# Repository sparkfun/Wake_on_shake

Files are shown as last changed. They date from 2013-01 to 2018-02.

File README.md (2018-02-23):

Wake on Shake
=============

[Wake on Shake  
*Wake on Shake (SEN-11447)*](https://www.sparkfun.com/products/11447)

The Wake-on-Shake, based on a concept by Nitzan Gadish of Analog Devices, combines the ATTiny2313A with the ADXL362 
low-power accelerometer to cut power to your project for long periods of time, all the while waiting for a shake or a bump and sipping <2uA at 3.7V

Wake-on-Shake firmware was compiled in WinAVR-20100110.  
Arduino example sketch was compiled in Arduino 1.6. 
Hardware was developed in EAGLE 6.3.0.

Repository Contents
-------------------

* **/Firmware** - Any firmware that the part ships with, 
* **/Hardware** - All Eagle design files (.brd, .sch, .STL)
* **/Production** - Test bed files and production panel files

Documentation
--------------
* **[Hookup Guide](https://learn.sparkfun.com/tutorials/wake-on-shake-hookup-guide)** - Basic hookup guide for the Wake-on-Shake.
* **[Project Tutorial](https://learn.sparkfun.com/tutorials/the-uncertain-7-cube)** - Project tutorial for the Wake-on-Shake.
  
License Information
-------------------
The hardware is released under [Creative Commons ShareAlike 4.0 International](https://creativecommons.org/licenses/by-sa/4.0/).
The code is beerware; if you see me (or any other SparkFun employee) at the local, and you've found our code helpful, please buy us a round!

Distributed as-is; no warranty is given.

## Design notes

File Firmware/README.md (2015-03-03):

Wake-on-Shake Firmware
========================

* **Neopixel_Wake-on-Shake_Demo** -Example Arduino Sketch using the Neopixel library.
* **SparkFun_Wake-on-Shake_Demo** -Example Arduino Sketch for basic LED control.
* **Wake-on-Shake_Firmware** -Firmware that comes preinstalled on the SparkFun Wake-on-Shake.

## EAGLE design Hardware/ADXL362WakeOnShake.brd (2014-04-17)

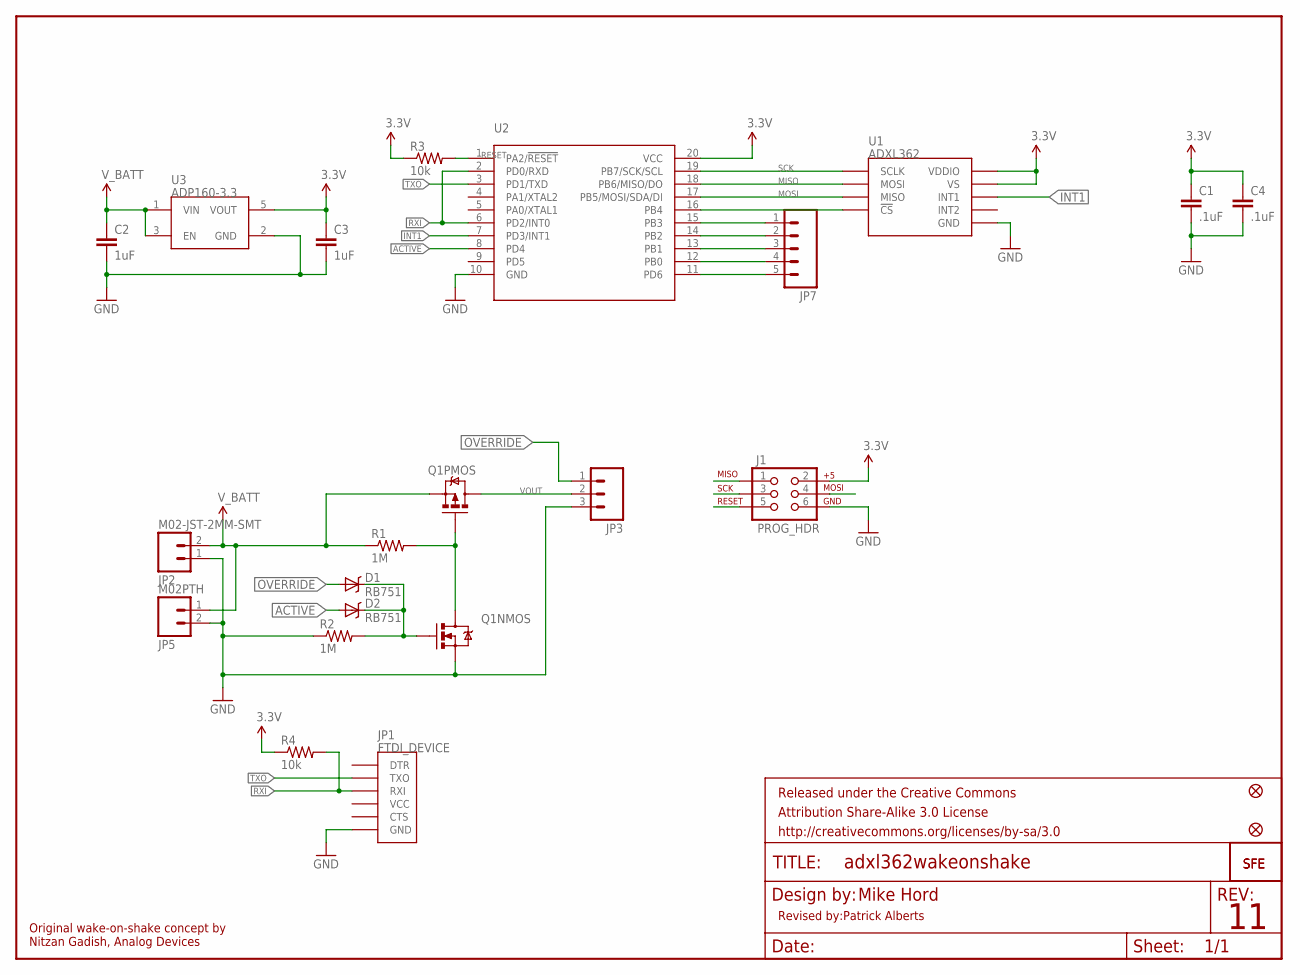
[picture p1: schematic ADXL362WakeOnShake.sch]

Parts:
C1, C4: .1uF; 0603-CAP
C2, C3: 1uF; 0603-CAP
D1, D2: RB751; SOD-523
FID1, FID2: FIDUCIAL1X2; FIDUCIAL-1X2
FRAME1: FRAME-LETTER; CREATIVE_COMMONS
J1: PROG_HDR; 2X3
JP1: FTDI_DEVICE; FTDI_DEVICE_SIDE
JP2: M02-JST-2MM-SMT; JST-2-SMD
JP3: M03PTH; 1X03
JP4: LOGO-SFENW2; SFE-NEW-WEB
JP5: M02PTH; 1X02
JP6: LOGO-SFENEW; SFE-NEW-WEBLOGO
JP7: M05PTH; 1X05
Q1: IRF7509; MSOP8
R1, R2: 1M; 0603-RES
R3, R4: 10k; 0603-RES
U1: ADXL362; ADXL362-1:1
U2: ATTINY2313A; SOP20W
U3: ADP160-3.3; SOT23-5

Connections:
3.3V: C1.1, C3.1, C4.1, J1.2, R3.1, R4.1, U1.P$1 (VDDIO), U1.P$14 (VS), U2.20 (VCC), U3.5 (VOUT)
ACTIVE: D2.A, U2.8 (PD4)
GND: C1.2, C2.2, C3.2, C4.2, J1.6, JP1.P$6 (GND), JP2.1 (2), JP3.3, JP5.2, Q1.1 (S), R2.1, U1.P$12 (GND), U1.P$13 (GND), U1.P$16 (GND), U2.10 (GND), U3.2 (GND)
INT1: U1.P$11 (INT1), U2.7 (PD3/INT1)
MISO: J1.1, U1.P$6 (MOSI), U2.18 (PB6/MISO/DO)
MOSI: J1.4, U1.P$7 (MISO), U2.17 (PB5/MOSI/SDA/DI)
unnamed: Q1.4 (G), Q1.7 (D), Q1.8 (D), R1.2
unnamed: D1.C, D2.C, Q1.2 (G), R2.2
unnamed: JP7.1, U2.15 (PB3)
unnamed: JP7.2, U2.14 (PB2)
unnamed: JP7.3, U2.13 (PB1)
unnamed: JP7.4, U2.12 (PB0)
unnamed: U1.P$8 (!CS), U2.16 (PB4)
unnamed: JP7.5, U2.11 (PD6)
OVERRIDE: D1.A, JP3.1
RESET: J1.5, R3.2, U2.1 (PA2/!RESET)
RXI: JP1.P$3 (RXI), R4.2, U2.2 (PD0/RXD), U2.6 (PD2/INT0)
SCK: J1.3, U1.P$4 (SCLK), U2.19 (PB7/SCK/SCL)
TXO: JP1.P$2 (TXO), U2.3 (PD1/TXD)
VOUT: JP3.2, Q1.5 (D), Q1.6 (D)
V_BATT: C2.1, JP2.2 (1), JP5.1, Q1.3 (S), R1.1, U3.1 (VIN), U3.3 (EN)

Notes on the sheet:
Mike Hord
Original wake-on-shake concept by Nitzan Gadish, Analog Devices
Revised by:Patrick Alberts

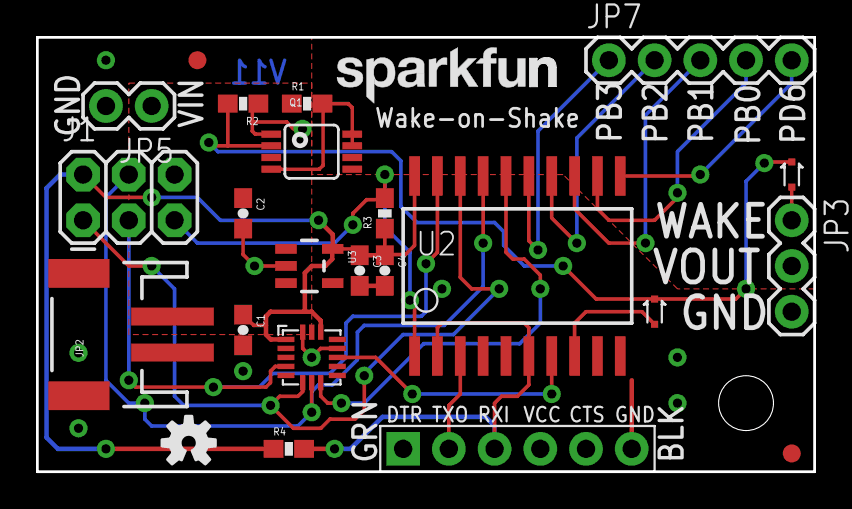
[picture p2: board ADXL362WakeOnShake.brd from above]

Board: 2 copper layers, 43.2 x 24.1 mm, 27 parts (1 on the bottom side), 21 nets.

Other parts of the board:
U$3: OSHW-LOGO-S
U$4: STAND-OFF-TIGHT

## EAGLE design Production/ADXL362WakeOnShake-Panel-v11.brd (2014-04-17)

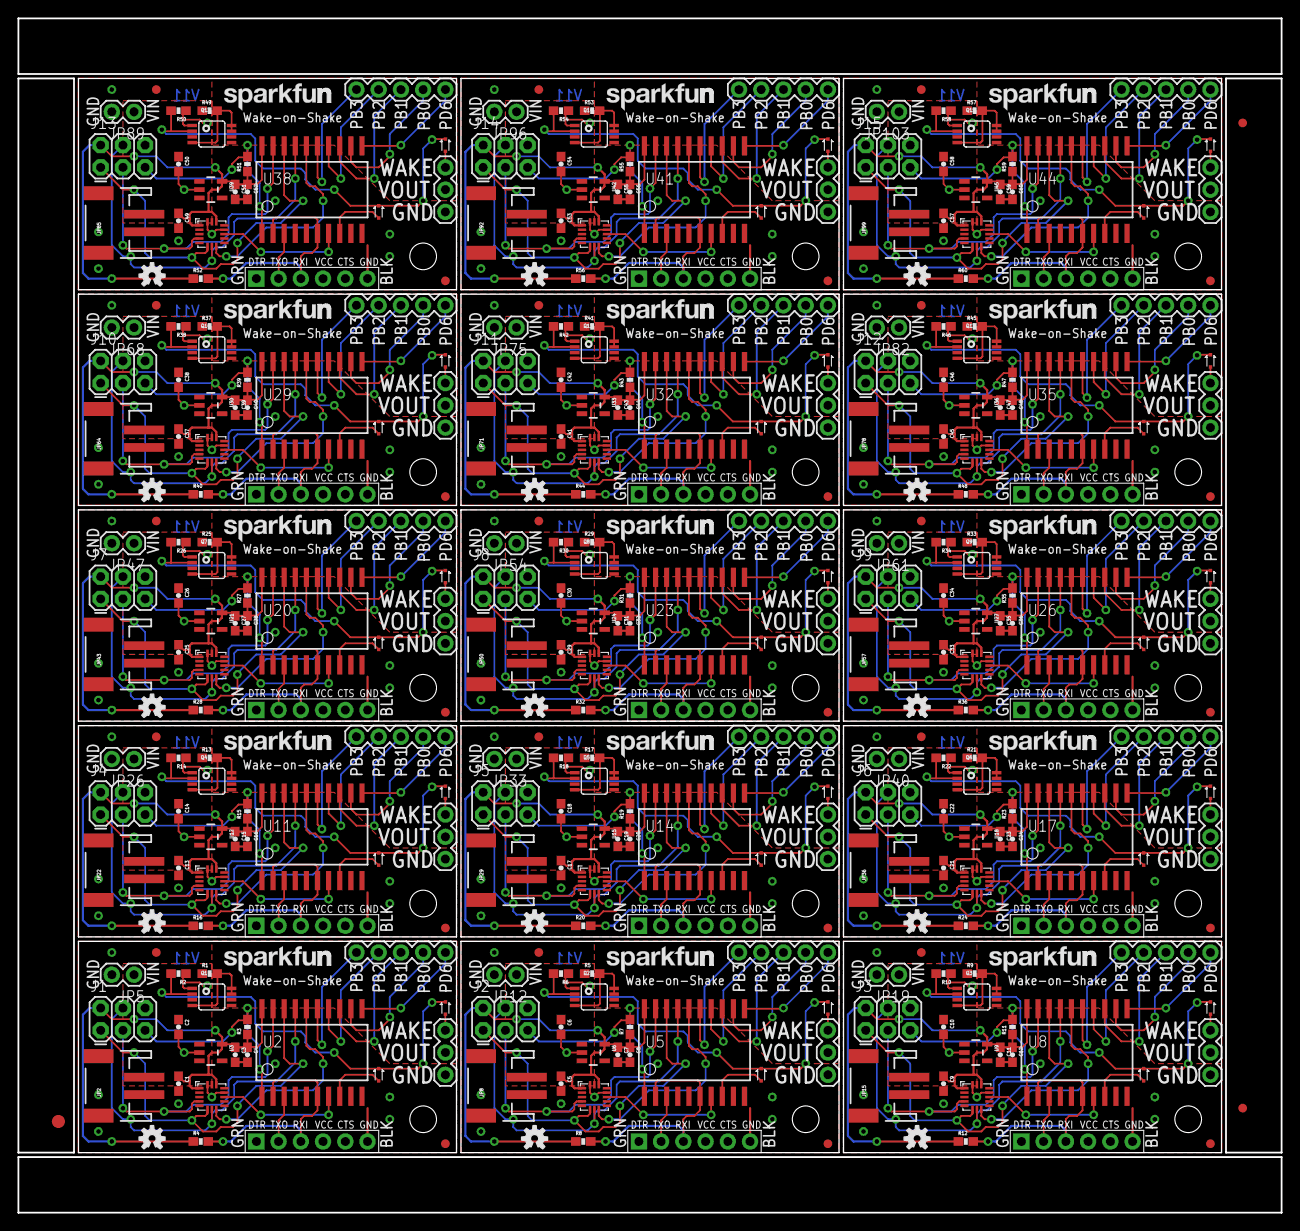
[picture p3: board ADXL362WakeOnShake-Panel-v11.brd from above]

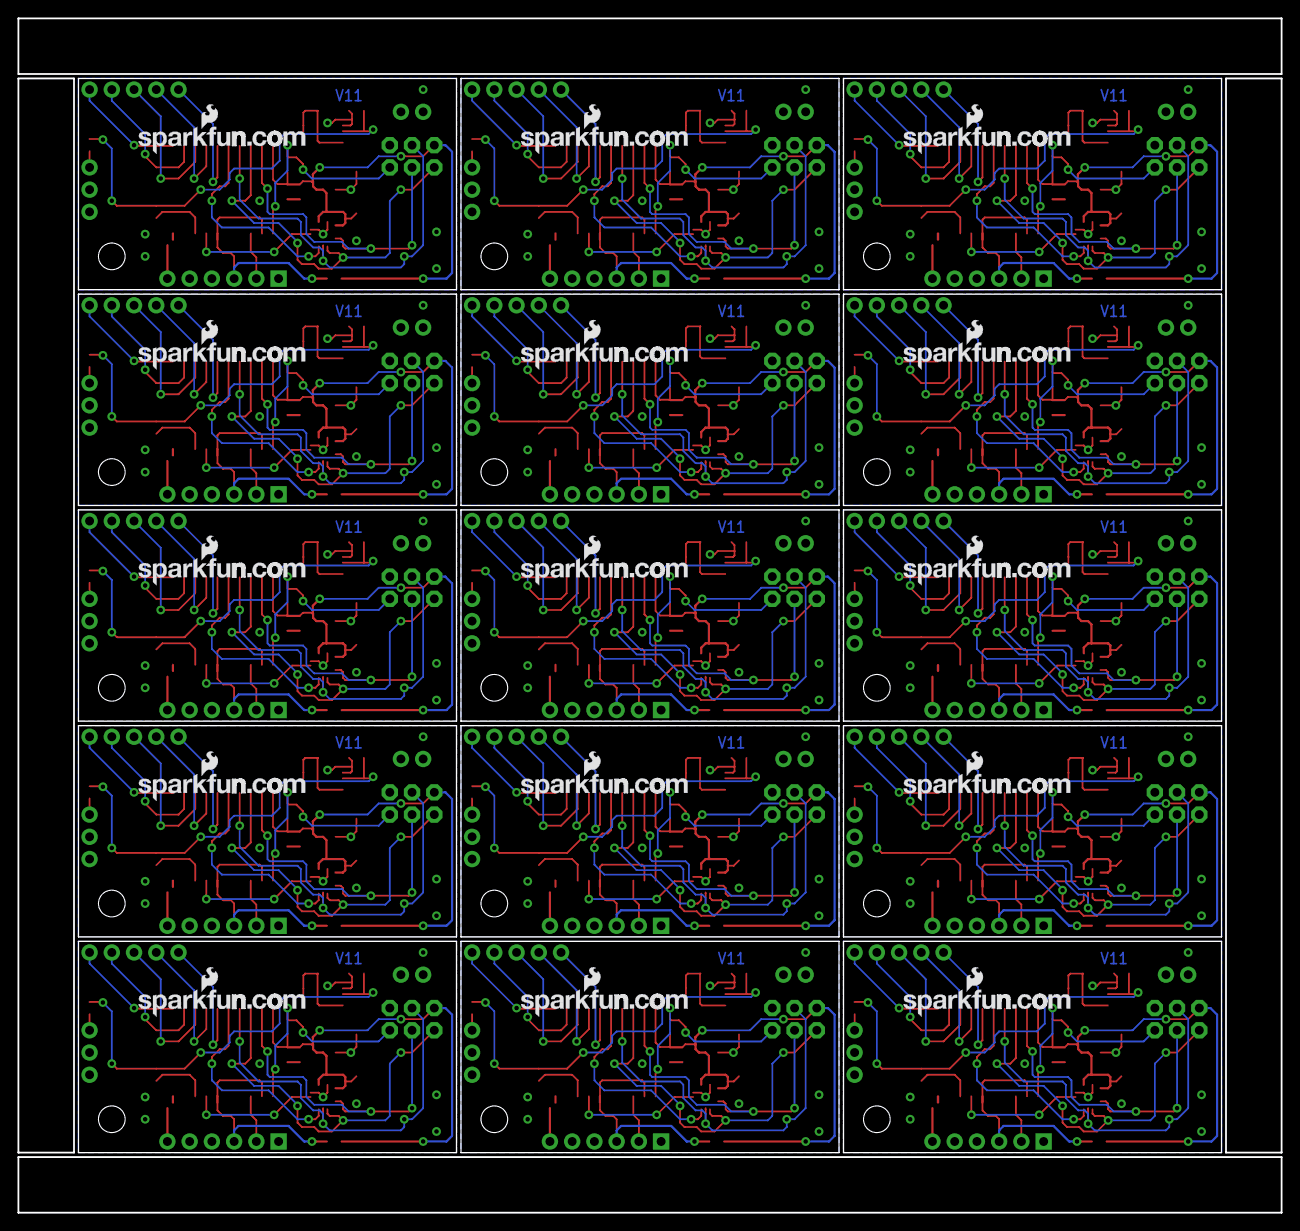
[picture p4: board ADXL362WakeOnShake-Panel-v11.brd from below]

Board: 2 copper layers, 144.3 x 136.4 mm, 393 parts (15 on the bottom side), 315 nets.

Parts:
C1, C4, C5, C8, C9, C12, C13, C16, C17, C20, C21, C24, C25, C28, C29, C32, C33, C36, C37, C40, C41, C44, C45, C48, C49, C52, C53, C56, C57, C60: .1uF; 0603-CAP
C2, C3, C6, C7, C10, C11, C14, C15, C18, C19, C22, C23, C26, C27, C30, C31, C34, C35, C38, C39, C42, C43, C46, C47, C50, C51, C54, C55, C58, C59: 1uF; 0603-CAP
D1, D2, D3, D4, D5, D6, D7, D8, D9, D10, D11, D12, D13, D14, D15, D16, D17, D18, D19, D20, D21, D22, D23, D24, D25, D26, D27, D28, D29, D30: RB751; SOD-523
E$1: FIDUCIAL-1.5X3
E$4, E$5: FIDUCIAL-1X2
FID1, FID2, FID3, FID4, FID5, FID6, FID7, FID8, FID9, FID10, FID11, FID12, FID13, FID14, FID15, FID16, FID17, FID18, FID19, FID20, FID21, FID22, FID23, FID24, FID25, FID26, FID27, FID28, FID29, FID30: FIDUCIAL1X2; FIDUCIAL-1X2
J1, J2, J3, J4, J5, J6, J7, J8, J9, J10, J11, J12, J13, J14, J15: PROG_HDR; 2X3
JP1, JP10, JP17, JP24, JP31, JP38, JP45, JP52, JP59, JP66, JP73, JP80, JP87, JP94, JP101: FTDI_DEVICE; FTDI_DEVICE_SIDE
JP2, JP8, JP15, JP22, JP29, JP36, JP43, JP50, JP57, JP64, JP71, JP78, JP85, JP92, JP99: M02-JST-2MM-SMT; JST-2-SMD
JP3, JP9, JP16, JP23, JP30, JP37, JP44, JP51, JP58, JP65, JP72, JP79, JP86, JP93, JP100: 1X03
JP4, JP11, JP18, JP25, JP32, JP39, JP46, JP53, JP60, JP67, JP74, JP81, JP88, JP95, JP102: LOGO-SFENW2; SFE-NEW-WEB
JP5, JP12, JP19, JP26, JP33, JP40, JP47, JP54, JP61, JP68, JP75, JP82, JP89, JP96, JP103: M02PTH; 1X02
JP6, JP13, JP20, JP27, JP34, JP41, JP48, JP55, JP62, JP69, JP76, JP83, JP90, JP97, JP104: LOGO-SFENEW; SFE-NEW-WEBLOGO
JP7, JP14, JP21, JP28, JP35, JP42, JP49, JP56, JP63, JP70, JP77, JP84, JP91, JP98, JP105: 1X05
Q1, Q2, Q3, Q4, Q5, Q6, Q7, Q8, Q9, Q10, Q11, Q12, Q13, Q14, Q15: MSOP8
R1, R2, R5, R6, R9, R10, R13, R14, R17, R18, R21, R22, R25, R26, R29, R30, R33, R34, R37, R38, R41, R42, R45, R46, R49, R50, R53, R54, R57, R58: 1M; 0603-RES
R3, R4, R7, R8, R11, R12, R15, R16, R19, R20, R23, R24, R27, R28, R31, R32, R35, R36, R39, R40, R43, R44, R47, R48, R51, R52, R55, R56, R59, R60: 10k; 0603-RES
U1, U4, U7, U10, U13, U16, U19, U22, U25, U28, U31, U34, U37, U40, U43: ADXL362; ADXL362-1:1
U2, U5, U8, U11, U14, U17, U20, U23, U26, U29, U32, U35, U38, U41, U44: SOP20W
U3, U6, U9, U12, U15, U18, U21, U24, U27, U30, U33, U36, U39, U42, U45: ADP160-3.3; SOT23-5
U$1, U$4, U$5, U$7, U$9, U$11, U$13, U$15, U$17, U$19, U$21, U$23, U$25, U$27, U$29: STAND-OFF-TIGHT
U$2, U$3, U$6, U$8, U$10, U$12, U$14, U$16, U$18, U$20, U$22, U$24, U$26, U$28, U$30: OSHW-LOGO-S

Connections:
3.3V: C1.1, C3.1, C4.1, J1.2, R3.1, R4.1, U1.P$1, U1.P$14, U2.20, U3.5
3.3V1: C5.1, C7.1, C8.1, J2.2, R7.1, R8.1, U4.P$1, U4.P$14, U5.20, U6.5
3.3V2: C9.1, C11.1, C12.1, J3.2, R11.1, R12.1, U7.P$1, U7.P$14, U8.20, U9.5
3.3V3: C13.1, C15.1, C16.1, J4.2, R15.1, R16.1, U10.P$1, U10.P$14, U11.20, U12.5
3.3V4: C17.1, C19.1, C20.1, J5.2, R19.1, R20.1, U13.P$1, U13.P$14, U14.20, U15.5
3.3V5: C21.1, C23.1, C24.1, J6.2, R23.1, R24.1, U16.P$1, U16.P$14, U17.20, U18.5
3.3V6: C25.1, C27.1, C28.1, J7.2, R27.1, R28.1, U19.P$1, U19.P$14, U20.20, U21.5
3.3V7: C29.1, C31.1, C32.1, J8.2, R31.1, R32.1, U22.P$1, U22.P$14, U23.20, U24.5
3.3V8: C33.1, C35.1, C36.1, J9.2, R35.1, R36.1, U25.P$1, U25.P$14, U26.20, U27.5
3.3V9: C37.1, C39.1, C40.1, J10.2, R39.1, R40.1, U28.P$1, U28.P$14, U29.20, U30.5
3.3V10: C41.1, C43.1, C44.1, J11.2, R43.1, R44.1, U31.P$1, U31.P$14, U32.20, U33.5
3.3V11: C45.1, C47.1, C48.1, J12.2, R47.1, R48.1, U34.P$1, U34.P$14, U35.20, U36.5
3.3V12: C49.1, C51.1, C52.1, J13.2, R51.1, R52.1, U37.P$1, U37.P$14, U38.20, U39.5
3.3V13: C53.1, C55.1, C56.1, J14.2, R55.1, R56.1, U40.P$1, U40.P$14, U41.20, U42.5
3.3V14: C57.1, C59.1, C60.1, J15.2, R59.1, R60.1, U43.P$1, U43.P$14, U44.20, U45.5
ACTIVE: D2.A, U2.8
ACTIVE1: D4.A, U5.8
ACTIVE2: D6.A, U8.8
ACTIVE3: D8.A, U11.8
ACTIVE4: D10.A, U14.8
ACTIVE5: D12.A, U17.8
ACTIVE6: D14.A, U20.8
ACTIVE7: D16.A, U23.8
ACTIVE8: D18.A, U26.8
ACTIVE9: D20.A, U29.8
ACTIVE10: D22.A, U32.8
ACTIVE11: D24.A, U35.8
ACTIVE12: D26.A, U38.8
ACTIVE13: D28.A, U41.8
ACTIVE14: D30.A, U44.8
GND: C1.2, C2.2, C3.2, C4.2, J1.6, JP1.P$6, JP2.1, JP3.3, JP5.2, Q1.1, R2.1, U1.P$12, U1.P$13, U1.P$16, U2.10, U3.2
GND1: C5.2, C6.2, C7.2, C8.2, J2.6, JP8.1, JP9.3, JP10.P$6, JP12.2, Q2.1, R6.1, U4.P$12, U4.P$13, U4.P$16, U5.10, U6.2
GND2: C9.2, C10.2, C11.2, C12.2, J3.6, JP15.1, JP16.3, JP17.P$6, JP19.2, Q3.1, R10.1, U7.P$12, U7.P$13, U7.P$16, U8.10, U9.2
GND3: C13.2, C14.2, C15.2, C16.2, J4.6, JP22.1, JP23.3, JP24.P$6, JP26.2, Q4.1, R14.1, U10.P$12, U10.P$13, U10.P$16, U11.10, U12.2
GND4: C17.2, C18.2, C19.2, C20.2, J5.6, JP29.1, JP30.3, JP31.P$6, JP33.2, Q5.1, R18.1, U13.P$12, U13.P$13, U13.P$16, U14.10, U15.2
GND5: C21.2, C22.2, C23.2, C24.2, J6.6, JP36.1, JP37.3, JP38.P$6, JP40.2, Q6.1, R22.1, U16.P$12, U16.P$13, U16.P$16, U17.10, U18.2
GND6: C25.2, C26.2, C27.2, C28.2, J7.6, JP43.1, JP44.3, JP45.P$6, JP47.2, Q7.1, R26.1, U19.P$12, U19.P$13, U19.P$16, U20.10, U21.2
GND7: C29.2, C30.2, C31.2, C32.2, J8.6, JP50.1, JP51.3, JP52.P$6, JP54.2, Q8.1, R30.1, U22.P$12, U22.P$13, U22.P$16, U23.10, U24.2
GND8: C33.2, C34.2, C35.2, C36.2, J9.6, JP57.1, JP58.3, JP59.P$6, JP61.2, Q9.1, R34.1, U25.P$12, U25.P$13, U25.P$16, U26.10, U27.2
GND9: C37.2, C38.2, C39.2, C40.2, J10.6, JP64.1, JP65.3, JP66.P$6, JP68.2, Q10.1, R38.1, U28.P$12, U28.P$13, U28.P$16, U29.10, U30.2
GND10: C41.2, C42.2, C43.2, C44.2, J11.6, JP71.1, JP72.3, JP73.P$6, JP75.2, Q11.1, R42.1, U31.P$12, U31.P$13, U31.P$16, U32.10, U33.2
GND11: C45.2, C46.2, C47.2, C48.2, J12.6, JP78.1, JP79.3, JP80.P$6, JP82.2, Q12.1, R46.1, U34.P$12, U34.P$13, U34.P$16, U35.10, U36.2
GND12: C49.2, C50.2, C51.2, C52.2, J13.6, JP85.1, JP86.3, JP87.P$6, JP89.2, Q13.1, R50.1, U37.P$12, U37.P$13, U37.P$16, U38.10, U39.2
GND13: C53.2, C54.2, C55.2, C56.2, J14.6, JP92.1, JP93.3, JP94.P$6, JP96.2, Q14.1, R54.1, U40.P$12, U40.P$13, U40.P$16, U41.10, U42.2
GND14: C57.2, C58.2, C59.2, C60.2, J15.6, JP99.1, JP100.3, JP101.P$6, JP103.2, Q15.1, R58.1, U43.P$12, U43.P$13, U43.P$16, U44.10, U45.2
INT1: U1.P$11, U2.7
INT2: U4.P$11, U5.7
INT3: U7.P$11, U8.7
INT4: U10.P$11, U11.7
INT5: U13.P$11, U14.7
INT6: U16.P$11, U17.7
INT7: U19.P$11, U20.7
INT8: U22.P$11, U23.7
INT9: U25.P$11, U26.7
INT10: U28.P$11, U29.7
INT11: U31.P$11, U32.7
INT12: U34.P$11, U35.7
INT13: U37.P$11, U38.7
INT14: U40.P$11, U41.7
INT15: U43.P$11, U44.7
MISO: J1.1, U1.P$6, U2.18
MISO1: J2.1, U4.P$6, U5.18
MISO2: J3.1, U7.P$6, U8.18
MISO3: J4.1, U10.P$6, U11.18
MISO4: J5.1, U13.P$6, U14.18
MISO5: J6.1, U16.P$6, U17.18
MISO6: J7.1, U19.P$6, U20.18
MISO7: J8.1, U22.P$6, U23.18
MISO8: J9.1, U25.P$6, U26.18
MISO9: J10.1, U28.P$6, U29.18
MISO10: J11.1, U31.P$6, U32.18
MISO11: J12.1, U34.P$6, U35.18
MISO12: J13.1, U37.P$6, U38.18
MISO13: J14.1, U40.P$6, U41.18
MISO14: J15.1, U43.P$6, U44.18
MOSI: J1.4, U1.P$7, U2.17
MOSI1: J2.4, U4.P$7, U5.17
MOSI2: J3.4, U7.P$7, U8.17
MOSI3: J4.4, U10.P$7, U11.17
MOSI4: J5.4, U13.P$7, U14.17
MOSI5: J6.4, U16.P$7, U17.17
MOSI6: J7.4, U19.P$7, U20.17
MOSI7: J8.4, U22.P$7, U23.17
MOSI8: J9.4, U25.P$7, U26.17
MOSI9: J10.4, U28.P$7, U29.17
MOSI10: J11.4, U31.P$7, U32.17
MOSI11: J12.4, U34.P$7, U35.17
MOSI12: J13.4, U37.P$7, U38.17
MOSI13: J14.4, U40.P$7, U41.17
MOSI14: J15.4, U43.P$7, U44.17
unnamed: Q1.4, Q1.7, Q1.8, R1.2
unnamed: D1.C, D2.C, Q1.2, R2.2
unnamed: JP7.1, U2.15
unnamed: JP7.2, U2.14
unnamed: JP7.3, U2.13
unnamed: JP7.4, U2.12
unnamed: U1.P$8, U2.16
unnamed: JP7.5, U2.11
unnamed: Q2.4, Q2.7, Q2.8, R5.2
unnamed: D3.C, D4.C, Q2.2, R6.2
unnamed: U4.P$8, U5.16
unnamed: JP14.1, U5.15
unnamed: JP14.2, U5.14
unnamed: JP14.3, U5.13
unnamed: JP14.4, U5.12
unnamed: JP14.5, U5.11
unnamed: Q3.4, Q3.7, Q3.8, R9.2
unnamed: D5.C, D6.C, Q3.2, R10.2
unnamed: U7.P$8, U8.16
unnamed: JP21.1, U8.15
unnamed: JP21.2, U8.14
unnamed: JP21.3, U8.13
unnamed: JP21.4, U8.12
unnamed: JP21.5, U8.11
unnamed: Q4.4, Q4.7, Q4.8, R13.2
unnamed: D7.C, D8.C, Q4.2, R14.2
unnamed: U10.P$8, U11.16
unnamed: JP28.1, U11.15
unnamed: JP28.2, U11.14
unnamed: JP28.3, U11.13
unnamed: JP28.4, U11.12
unnamed: JP28.5, U11.11
unnamed: Q5.4, Q5.7, Q5.8, R17.2
unnamed: D9.C, D10.C, Q5.2, R18.2
unnamed: U13.P$8, U14.16
unnamed: JP35.1, U14.15
unnamed: JP35.2, U14.14
unnamed: JP35.3, U14.13
unnamed: JP35.4, U14.12
unnamed: JP35.5, U14.11
unnamed: Q6.4, Q6.7, Q6.8, R21.2
unnamed: D11.C, D12.C, Q6.2, R22.2
unnamed: U16.P$8, U17.16
unnamed: JP42.1, U17.15
unnamed: JP42.2, U17.14
unnamed: JP42.3, U17.13
unnamed: JP42.4, U17.12
unnamed: JP42.5, U17.11
unnamed: Q7.4, Q7.7, Q7.8, R25.2
unnamed: D13.C, D14.C, Q7.2, R26.2
unnamed: U19.P$8, U20.16
unnamed: JP49.1, U20.15
unnamed: JP49.2, U20.14
unnamed: JP49.3, U20.13
unnamed: JP49.4, U20.12
unnamed: JP49.5, U20.11
unnamed: Q8.4, Q8.7, Q8.8, R29.2
unnamed: D15.C, D16.C, Q8.2, R30.2
unnamed: U22.P$8, U23.16
unnamed: JP56.1, U23.15
unnamed: JP56.2, U23.14
unnamed: JP56.3, U23.13
unnamed: JP56.4, U23.12
unnamed: JP56.5, U23.11
unnamed: Q9.4, Q9.7, Q9.8, R33.2
unnamed: D17.C, D18.C, Q9.2, R34.2
unnamed: U25.P$8, U26.16
unnamed: JP63.1, U26.15
unnamed: JP63.2, U26.14
unnamed: JP63.3, U26.13
unnamed: JP63.4, U26.12
unnamed: JP63.5, U26.11
unnamed: Q10.4, Q10.7, Q10.8, R37.2
unnamed: D19.C, D20.C, Q10.2, R38.2
unnamed: U28.P$8, U29.16
unnamed: JP70.1, U29.15
unnamed: JP70.2, U29.14
unnamed: JP70.3, U29.13
unnamed: JP70.4, U29.12
unnamed: JP70.5, U29.11
unnamed: Q11.4, Q11.7, Q11.8, R41.2
unnamed: D21.C, D22.C, Q11.2, R42.2
unnamed: U31.P$8, U32.16
unnamed: JP77.1, U32.15
unnamed: JP77.2, U32.14
unnamed: JP77.3, U32.13
unnamed: JP77.4, U32.12
unnamed: JP77.5, U32.11
unnamed: Q12.4, Q12.7, Q12.8, R45.2
unnamed: D23.C, D24.C, Q12.2, R46.2
unnamed: U34.P$8, U35.16
unnamed: JP84.1, U35.15
unnamed: JP84.2, U35.14
unnamed: JP84.3, U35.13
unnamed: JP84.4, U35.12
unnamed: JP84.5, U35.11
unnamed: Q13.4, Q13.7, Q13.8, R49.2
unnamed: D25.C, D26.C, Q13.2, R50.2
unnamed: U37.P$8, U38.16
unnamed: JP91.1, U38.15
unnamed: JP91.2, U38.14
unnamed: JP91.3, U38.13
unnamed: JP91.4, U38.12
unnamed: JP91.5, U38.11
unnamed: Q14.4, Q14.7, Q14.8, R53.2
unnamed: D27.C, D28.C, Q14.2, R54.2
unnamed: U40.P$8, U41.16
unnamed: JP98.1, U41.15
unnamed: JP98.2, U41.14
unnamed: JP98.3, U41.13
unnamed: JP98.4, U41.12
unnamed: JP98.5, U41.11
unnamed: Q15.4, Q15.7, Q15.8, R57.2
unnamed: D29.C, D30.C, Q15.2, R58.2
unnamed: U43.P$8, U44.16
unnamed: JP105.1, U44.15
unnamed: JP105.2, U44.14
unnamed: JP105.3, U44.13
unnamed: JP105.4, U44.12
unnamed: JP105.5, U44.11
OVERRIDE: D1.A, JP3.1
OVERRIDE1: D3.A, JP9.1
OVERRIDE2: D5.A, JP16.1
OVERRIDE3: D7.A, JP23.1
OVERRIDE4: D9.A, JP30.1
OVERRIDE5: D11.A, JP37.1
OVERRIDE6: D13.A, JP44.1
OVERRIDE7: D15.A, JP51.1
OVERRIDE8: D17.A, JP58.1
OVERRIDE9: D19.A, JP65.1
OVERRIDE10: D21.A, JP72.1
OVERRIDE11: D23.A, JP79.1
OVERRIDE12: D25.A, JP86.1
OVERRIDE13: D27.A, JP93.1
OVERRIDE14: D29.A, JP100.1
RESET: J1.5, R3.2, U2.1
RESET1: J2.5, R7.2, U5.1
RESET2: J3.5, R11.2, U8.1
RESET3: J4.5, R15.2, U11.1
RESET4: J5.5, R19.2, U14.1
RESET5: J6.5, R23.2, U17.1
RESET6: J7.5, R27.2, U20.1
RESET7: J8.5, R31.2, U23.1
RESET8: J9.5, R35.2, U26.1
RESET9: J10.5, R39.2, U29.1
RESET10: J11.5, R43.2, U32.1
RESET11: J12.5, R47.2, U35.1
RESET12: J13.5, R51.2, U38.1
RESET13: J14.5, R55.2, U41.1
RESET14: J15.5, R59.2, U44.1
RXI: JP1.P$3, R4.2, U2.2, U2.6
RXI1: JP10.P$3, R8.2, U5.2, U5.6
RXI2: JP17.P$3, R12.2, U8.2, U8.6
RXI3: JP24.P$3, R16.2, U11.2, U11.6
RXI4: JP31.P$3, R20.2, U14.2, U14.6
RXI5: JP38.P$3, R24.2, U17.2, U17.6
RXI6: JP45.P$3, R28.2, U20.2, U20.6
RXI7: JP52.P$3, R32.2, U23.2, U23.6
RXI8: JP59.P$3, R36.2, U26.2, U26.6
RXI9: JP66.P$3, R40.2, U29.2, U29.6
RXI10: JP73.P$3, R44.2, U32.2, U32.6
RXI11: JP80.P$3, R48.2, U35.2, U35.6
RXI12: JP87.P$3, R52.2, U38.2, U38.6
RXI13: JP94.P$3, R56.2, U41.2, U41.6
RXI14: JP101.P$3, R60.2, U44.2, U44.6
SCK: J1.3, U1.P$4, U2.19
SCK1: J2.3, U4.P$4, U5.19
SCK2: J3.3, U7.P$4, U8.19
SCK3: J4.3, U10.P$4, U11.19
SCK4: J5.3, U13.P$4, U14.19
SCK5: J6.3, U16.P$4, U17.19
SCK6: J7.3, U19.P$4, U20.19
SCK7: J8.3, U22.P$4, U23.19
SCK8: J9.3, U25.P$4, U26.19
SCK9: J10.3, U28.P$4, U29.19
SCK10: J11.3, U31.P$4, U32.19
SCK11: J12.3, U34.P$4, U35.19
SCK12: J13.3, U37.P$4, U38.19
SCK13: J14.3, U40.P$4, U41.19
SCK14: J15.3, U43.P$4, U44.19
TXO: JP1.P$2, U2.3
TXO1: JP10.P$2, U5.3
TXO2: JP17.P$2, U8.3
TXO3: JP24.P$2, U11.3
TXO4: JP31.P$2, U14.3
TXO5: JP38.P$2, U17.3
TXO6: JP45.P$2, U20.3
TXO7: JP52.P$2, U23.3
TXO8: JP59.P$2, U26.3
TXO9: JP66.P$2, U29.3
TXO10: JP73.P$2, U32.3
TXO11: JP80.P$2, U35.3
TXO12: JP87.P$2, U38.3
TXO13: JP94.P$2, U41.3
TXO14: JP101.P$2, U44.3
VOUT: JP3.2, Q1.5, Q1.6
VOUT1: JP9.2, Q2.5, Q2.6
VOUT2: JP16.2, Q3.5, Q3.6
VOUT3: JP23.2, Q4.5, Q4.6
VOUT4: JP30.2, Q5.5, Q5.6
VOUT5: JP37.2, Q6.5, Q6.6
VOUT6: JP44.2, Q7.5, Q7.6
VOUT7: JP51.2, Q8.5, Q8.6
VOUT8: JP58.2, Q9.5, Q9.6
VOUT9: JP65.2, Q10.5, Q10.6
VOUT10: JP72.2, Q11.5, Q11.6
VOUT11: JP79.2, Q12.5, Q12.6
VOUT12: JP86.2, Q13.5, Q13.6
VOUT13: JP93.2, Q14.5, Q14.6
VOUT14: JP100.2, Q15.5, Q15.6
V_BATT: C2.1, JP2.2, JP5.1, Q1.3, R1.1, U3.1, U3.3
V_BATT1: C6.1, JP8.2, JP12.1, Q2.3, R5.1, U6.1, U6.3
V_BATT2: C10.1, JP15.2, JP19.1, Q3.3, R9.1, U9.1, U9.3
V_BATT3: C14.1, JP22.2, JP26.1, Q4.3, R13.1, U12.1, U12.3
V_BATT4: C18.1, JP29.2, JP33.1, Q5.3, R17.1, U15.1, U15.3
V_BATT5: C22.1, JP36.2, JP40.1, Q6.3, R21.1, U18.1, U18.3
V_BATT6: C26.1, JP43.2, JP47.1, Q7.3, R25.1, U21.1, U21.3
V_BATT7: C30.1, JP50.2, JP54.1, Q8.3, R29.1, U24.1, U24.3
V_BATT8: C34.1, JP57.2, JP61.1, Q9.3, R33.1, U27.1, U27.3
V_BATT9: C38.1, JP64.2, JP68.1, Q10.3, R37.1, U30.1, U30.3
V_BATT10: C42.1, JP71.2, JP75.1, Q11.3, R41.1, U33.1, U33.3
V_BATT11: C46.1, JP78.2, JP82.1, Q12.3, R45.1, U36.1, U36.3
V_BATT12: C50.1, JP85.2, JP89.1, Q13.3, R49.1, U39.1, U39.3
V_BATT13: C54.1, JP92.2, JP96.1, Q14.3, R53.1, U42.1, U42.3
V_BATT14: C58.1, JP99.2, JP103.1, Q15.3, R57.1, U45.1, U45.3

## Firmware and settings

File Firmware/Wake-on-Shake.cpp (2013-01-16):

/******************************************************************************
Created 26 Nov 2012 by Mike Hord at SparkFun Electronics.
Wake-on-Shake hardware and firmware are released under the Creative Commons 
Share Alike v3.0 license:
	http://creativecommons.org/licenses/by-sa/3.0/
Feel free to use, distribute, and sell variants of Wake-on-Shake. All we ask 
is that you include attribution of 'Based on Wake-on-Shake by SparkFun'.

Wake-on-Shake is a simple but powerful board designed to power up a larger
circuit when it detects motion. The load has the option of holding its power
even after the Wake-on-Shake releases it, so the load circuit can complete its
"mission".

It also provides a very simple UI which can be used to set the time before
shutdown and wake-up sensitivity. There are other, more powerful features
available, but most users will not need them.

******************************************************************************/

//avrdude -p t2313 -P usb -c avrispmkii -U flash:w:Wake-on-Shake.hex -U hfuse:w:0xdf:m -U lfuse:w:0x64:m

#include <avr/io.h>
#include <avr/sleep.h>
#include <avr/interrupt.h>
#include "serial.h"
#include "eeprom.h"
#include "wake-on-shake.h"
#include "interrupts.h"
#include "spi.h"
#include "ADXL362.h"
#include "xl362.h"
#include "ui.h"

uint16_t			t1Offset;			// This value, when written to TCNT1, 
										//   is the offset to the delay before
										//   sleep. It is 65535 - (delay)ms.
volatile bool		sleepyTime = false; // Flag used to communicate from the
										//   ISR to the main program to send
										//   the device into sleep mode.
volatile uint8_t    serialRxData = 0;	// Data passing variable to get data
										//   from the receive ISR back to main.
										
// main(). If you don't know what this is, you need to do some serious
//  work on your fundamentals.

int main(void)
{
	// First, let's configure the directions (in/out) of the various pins. Writing a
	//   '1' to the appropriate bit in a DDRx register will render that pin an
	//   output.
	
	// Port A- both pins are unused, so we'll make them both outputs and drive them
	//   low to save power.
	DDRA = (1<<PA1) | (1<<PA0);
	// Port B- PB0-3 are unused; make them outputs and tie them low. PB4 is !CS
	//   for the ADXL362, so it should be an output. PB5 is MISO from the ADXL362, so
	//   leave it an input. PB6 is MOSI to ADXL362, and PB7 is SCK, so they should be
	//   outputs.
	DDRB = (1<<PB7) | (1<<PB6) | (1<<PB4) | (1<<PB3) | (1<<PB2)| (1<<PB1) | (1<<PB0);
	// No port C pins on this chip
	// Port D- PD0 is the serial receive input. PD1 is serial transmit output. PD2 is
	//   is an external interrupt used to wake the processor on serial activity. PD3
	//   is the interrupt from the ADXL362, used to wake the device on detected
	//   motion. PD4 is the MOSFET turn-on signal, so should be an output. PD5 and
	//   PD6 are unused; make them outputs and tie them low. PD7 doesn't exist.
	DDRD = (1<<PD6) | (1<<PD5) | (1<<PD4) | (1<<PD1);
	
	// Now let's configure some initial IO states
	
	// Port A- both set low to reduce current consumption
	PORTA = (0<<PA1) | (0<<PA0);
	// Port B- PB0-3 should be low for power consumption; PB4 is !CS, so bring it
	//   high to keep the ADXL362 non-selected. Others are don't care.
	PORTB = (1<<PB4) | (0<<PB3) | (0<<PB2) | (0<<PB1) | (0<<PB0);
	// Port C doesn't exist
	// Port D- PD5 and PD6 should be tied low; others are (for now) don't care.
	//   Also, PD2/PD0 should be made high to enable pullup resistor for when no
	//   serial connection is present.
	PORTD = (1<<PD6) | (1<<PD5) | (1<<PD2) | (1<<PD0);
	
	// Interrupt configuration is next. We'll need two interrupts: INT0 and INT1.
	//   INT0 will wiggle when a serial connection occurs. INT1 will wiggle when
	//   the ADXL362 detects motion and wakes up.
	
	// MCUCR- Bits 0:3 control the interrupt event we want to be sensitive to.
	//   We'll set it so a low level is what each pin is looking for.
	MCUCR = (0<<ISC11) | (0<<ISC10) | (0<<ISC01) | (0<<ISC00);
	// GIMSK- These are mask bits for the pin change interrupts. Writing a '1'
	//   enables the appropriate interrupt.
	GIMSK = (0<<INT1) | (0<<INT0);
	
	// Now, set up the USI peripheral for communication with the ADXL362 part.
	//   The ADXL362 uses SPI Mode 0- CPHA = CPOL = 0.
	
	// UISCR- USWM1:0 are mode select pins; 01 is three-wire mode.
	//   USICS1:0 are clock source select pins; 10 is software control.
	//   USICLK puts the 4-bit data counter under software control.
	//   Strobing USITC toggles the 4-bit clock signal.
	USICR = (0<<USIWM1) | (1<<USIWM0) | (1<<USICS1) | (0<<USICS0) | (1<<USICLK);
	// USISR- Writing '1' to USIOIF will clear the 4-bit counter overflow
	//   flag and ready it for the next transfer. Implicit here is a write
	//   of zeroes to bits 3:0 of this register, which also clears the 4-bit
	//   counter.
	USISR = (1<<USIOIF);
	
	// Set up the USART peripheral for writing in and out. This isn't used
	//   during normal operation- only during user configuration. We'll
	//   set the mode to 2400 baud, 8-N-1. Pretty standard, really.

	// For 2400 baud, at 1.000MHz (which is our clock speed, since we're
	//   using the internal oscillator clocked down), UBRR should be set to
	//   25, and the U2X bit of UCSRA should be set to '0'.
	UBRRH = 0;
	UBRRL = 25;
	UCSRA = (0<<U2X);
	// UCSRB- RXEN and TXEN enable the transmit and receive circuitry.
	//   UCSZ2 is a frame size bit; when set to 0 (as here), the size is
	//   determined by UCSZ1:0 in UCSRC. RXCIE is the receive interrupt
	//   enable bit; we want that interrupt for handling incoming settings
	//   changes while the part is awake.
	UCSRB = (1<<RXCIE) | (1<<RXEN) | (1<<TXEN);
	// UCSRC- Setting UCSZ1:0 to '1' gives us an 8-bit frame size. There
	//   are provisions in this register for synchronous mode, parity,
	//   and stop-bit count, but we'll ignore them.
	UCSRC = (1<<UCSZ1) | (1<<UCSZ0);

	// set_sleep_mode() is a nice little macro from the sleep library which
	//   sets the stage nicely for sleep; after this, all you need to do is
	//   call sleep_mode() to put the processor to sleep. Power Down mode is
	//   the lowest possible sleep power state; all clocks are stopped and
	//   only an external interrupt can wake the processor.
	set_sleep_mode(SLEEP_MODE_PWR_DOWN);
	
	// Check to make sure the EEPROM has been configured for first use by
	//   looking at the "key" location. If not, configure it.
	if (EEPROMReadByte((uint8_t)KEY_ADDR) != KEY) EEPROMConfig();
	
	// EEPROMRetrieve() pulls the various operational parameters out of
	//   EEPROM and puts them in SRAM.
	EEPROMRetrieve();
	
	// Configure the ADXL362 with the info we just pulled from EEPROM.
	ADXLConfig();

	// We need to set up Timer1 as an overflow interrupt so the device can
	//   stay awake long enough for the user to input some parameters.
	//   Timer1 is a 16-bit counter; I'm going to set it up so that it ticks
	//   over every 10 seconds when the device is awake, and when it ticks,
	//   the device drops back into sleep.
	// TCCR1B- 101 in CS1 bits divides the clock by 1024; ~one count per ms.
	TCCR1B = (1<<CS12) | (0<<CS11) | (1<<CS10);
	// TCNT1- When this hits 65,536, an overflow interrupt occurs. By
	//   "priming" it, we reduce the time until an interrupt occurs.
	//   The if/else is to prevent the user accidentally
	//   setting it so low that the part goes back to sleep before it can be
	//   reprogrammed by the user through the command line.
	TCNT1 = t1Offset;
	// TIMSK- Set TOIE1 to enable Timer1 overflow interrupt
	TIMSK = (1<<TOIE1);
	
	// loadOn() is a simple function that turns on the load. We'll turn it on
	//   now and leave it on until sleep.
	loadOn();
		
	// sei() is a macro that basically executes the single instruction
	//   global interrupt enable function. Up until now, interrupt sources
	//   are ignored. We will turn this on and leave it on, unless we need
	//   to perform some sensitive tasks which require interrupts disabled
	//   for a time.
	sei();
	
	// Okay, now we can move forward with our main application code. This loop
	//   will just run over and over forever, waiting for signals from interrupts
	//   to tell it what to do.
	printMenu();
	while(1)
	{
		// The main functionality is to go to sleep when there's been no activity
		//   for some time; if Timer1 manages to overflow, it will set sleepyTime
		//   true.
		if (sleepyTime)
		{
			serialWrite("z");			// Let the user know sleep mode is coming.
			ADXLConfig();
			GIMSK = (1<<INT0) |(1<<INT1);// Enable external interrupts to wake the
										//   processor up; INT0 is incoming serial
										//   data, INT1 is accelerometer interrupt
			loadOff();					// Turn off the load for sleepy time.
			sleep_mode();				// Go to sleep until awoken by an interrupt.
			printMenu();
			EEPROMRetrieve();			// Retrieve EEPROM values, mostly to print
										//   them out to the user, if the wake-up
										//   was due to serial data arriving.
			loadOn();					// Turn the load back on.
		}
		// Any data arriving over the serial port will trigger a serial receive
		//   interrupt. If that data is non-null, serialParse() will be called to
		//   deal with it.
		if (serialRxData != 0) serialParse();
	}
}

// Utility function which pulls the various operational paramters out of EEPROM,
//   puts them into SRAM, and prints them over the serial line.
void EEPROMRetrieve(void)
{
	uint16_t threshold = EEPROMReadWord((uint8_t)ATHRESH);		// Activity threshold. See
														//   ADXL362 datasheet for info.
	t1Offset =  EEPROMReadWord((uint8_t)WAKE_OFFS);     // (65535 - t1Offset)ms elapse
														//   between Timer1 interrupts.
	serialWriteInt(threshold);							// Print threshold in human format.
	serialWriteInt(65535 - t1Offset);					// Print the delay before sleep
														//   in human format.
}

// Configuration function for EEPROM- "erased" for the EEPROM is 65535, so we need to
//   change these to more manageable values the first time the board powers up, or the
//   sleep interrupt will happen WAY too fast and the motion threshold will be WAY too
//   high for practicality.
void EEPROMConfig(void)
{
	t1Offset  = 60535;		// Corresponds to ~5s delay before going to sleep
	// Now let's store these, along with the "key" that let's us know we've done this.
	EEPROMWriteWord((uint8_t)ATHRESH, (uint16_t) 150);
	EEPROMWriteWord((uint8_t)WAKE_OFFS, (uint16_t)t1Offset);
	EEPROMWriteWord((uint8_t)ITHRESH, (uint16_t)50);
	EEPROMWriteWord((uint8_t)ITIME, (uint16_t)15);
	EEPROMWriteByte((uint8_t)KEY_ADDR, (uint8_t)KEY);
}

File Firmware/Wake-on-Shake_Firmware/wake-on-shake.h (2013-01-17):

/******************************************************************************
Created 26 Nov 2012 by Mike Hord at SparkFun Electronics.
Wake-on-Shake hardware and firmware are released under the Creative Commons 
Share Alike v3.0 license:
	http://creativecommons.org/licenses/by-sa/3.0/
Feel free to use, distribute, and sell variants of Wake-on-Shake. All we ask 
is that you include attribution of 'Based on Wake-on-Shake by SparkFun'.

wake-on-shake.h
This is the main definitions file for the core code in the project. The few
functions in here are all basically convenience aggregations of calls to
functions in other places.
******************************************************************************/

#ifndef _wake_on_shake_h_included
#define _wake_on_shake_h_included
	  
void EEPROMRetrieve(void);	// Pulls config values out of EEPROM and displays.
void EEPROMConfig(void);	// Set the EEPROM storage locations up if they
							//   aren't already configured.

#define ATHRESH		0		// EEPROM address for the activity threshold.
#define WAKE_OFFS	2		// EEPROM address for the wake offset.
#define ITHRESH		4		// EEPROM address for the inactivity threshold.
#define ITIME		6		// EEPROM address for the activity time.
#define KEY_ADDR	127		// EEPROM address for the EEPROM configuration key.
#define KEY         123		// EEPROM configuration key value.

// Macros for turning the load on and off.
#define loadOff() PORTD &= !(1<<PD4)
#define loadOn()  PORTD |= (1<<PD4)

#define TRUE 1
#define FALSE 0

#endif

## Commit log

2012-10-10 Initial commit. Board v02, firmware not completed.
    [ADXL362WakeOnShake.brd, ADXL362WakeOnShake.sch]
2012-11-15 Initial firmware commit (for non-Arduino based stuff).
    This is an AVRStudio6 project; right now, all the pieces are working (serial,
    EEPROM, SPI, interrupts, etc etc), but the bits aren't tied together very
    well. The UI doesn't really work all that well.
    [ADXL362WakeOnShake.brd, ADXL362WakeOnShake.sch]
2012-11-15 Things playing more nicely, now. Readback from EEPROM produces wrong values; not sure if it's bad write or bad read or both.
    Interrupts greatly simplified; size of RX interrupt was causing either
    a non-reentrant code error or a stack overflow.
    [Wake-on-Shake.cpp, wake-on-shake.h]
2012-11-16 Hasn't been tested yet, and needs some comments placed into the code.
    Core functionality is in place and it seems to be working okay, though.
    [ADXL362WakeOnShake.brd, TcfTransactionLog.csv]
2012-11-19 Updating hardware files to v10: - FTDI header silk changed to accurately reflect pin names - moved some traces to avoid silk/via collision - added 10k resistor pull-up on RX line - FTDI header was sl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
    Changes to Firmware are purely machine changes to project files.
    [ADXL362WakeOnShake.brd, ADXL362WakeOnShake.sch]
2012-11-20 Tweaked the silk slightly so that there is a distinction between VIN and VOUT instead of them being both V+.
    [ADXL362WakeOnShake.brd]
2012-11-20 Added part number info for the accelerometer and changed the version number on the bottom copper layer.
    [ADXL362WakeOnShake.brd, ADXL362WakeOnShake.sch]
2013-01-16 Deleted AVR Studio crap.
    [TcfTransactionLog.csv]
2013-01-17 Go back to the AVR Studio version
    [TcfTransactionLog.csv]
2013-01-17 Okay, I really made a dog's dinner of this.
    Apparently, the last *useful* commit was actually pretty incomplete.
    I managed to delete a few important files, revert some stuff, and
    generally just screw up my life. Fortunately, Windows (or maybe
    Dropbox?) was able to take me back to a version of the folder from
    last week, before I started on this ill-fated comedy of errors.
    This commit effectively removes the AVR studio junk and moves all
    the source files from the AVR studio tree directly to the Firmware
    directory. *Now* I can start the process of getting it to compile
    and load properly apart from AVR Studio's toolchain.
    [TcfTransactionLog.csv]
2013-01-17 Production release candidate.
    -Converted .cpp files to .c
    -Converted UTF-8 encoded files to ANSI
    -Added a newline command to serial to save size
    -Changed some print messages to reduce size
2013-01-18 Minor updates - Fixed spelling errors in user guide. - Fixed minor issues in the ui.c
    [ui.c]
2013-01-22 Fixed some issues in the pin read/write functions in ui.c: - Write low was using logical NOT (!) instead of bitwise NOT (~) which was causing it to clear all pins instead of just one. - Read was usin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
    [ui.c]
2013-01-24 A few minor changes: - One of the function prototypes in ADXL362.h had a typo. - Increased the baud rate from 2400bps to 9600bps because the Arduino software serial library doesn't seem to like 2400b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
    [ADXL362WakeOnShake.brd]
2013-02-15 Added attribution for original concept.
    [ADXL362WakeOnShake.brd, ADXL362WakeOnShake.sch]
2014-02-12 Updated caps, res, sch, vers# and diodes
    Updated caps/res to 0603 , 1:1 on the adxl362, updated footprint for
    diodes, new rev #
    [ADXL362WakeOnShake.brd, ADXL362WakeOnShake.sch]
2014-03-21 Fixed FDTI ann rings / added standoff
    [ADXL362WakeOnShake.brd, ADXL362WakeOnShake.sch]
2014-04-17 added regular fiducials
    [ADXL362WakeOnShake.brd, ADXL362WakeOnShake.sch]
2014-04-17 Created panel v11
    [ADXL362WakeOnShake-Panel-v11.brd]
2015-03-03 Uploading example code for new Learn tutorial
    [ADXL362WakeOnShake-Panel-v11.brd]
2017-01-02 Fixing 'nix builds (Case-Sensitive)

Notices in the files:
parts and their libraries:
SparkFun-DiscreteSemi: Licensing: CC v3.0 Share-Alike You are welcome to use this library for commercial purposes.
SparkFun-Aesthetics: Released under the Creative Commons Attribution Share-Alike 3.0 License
